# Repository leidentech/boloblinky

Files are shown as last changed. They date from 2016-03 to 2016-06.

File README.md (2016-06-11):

# Boloblinky retro game device made with a max7219 LED matrix and Arduino Nano

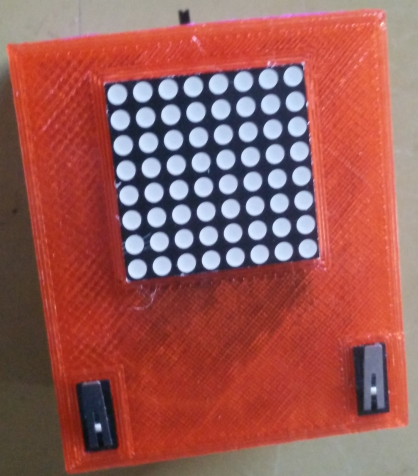
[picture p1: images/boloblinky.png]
boloblinky Boloblinky


I originally made this as a swag bag tchotchke for my 11-year-old son's birthday party.  It is designed so that the kids could build it themselves and get an introduction to soldering and acquainted with micro-controllers, programming and making stuff. My only two design parameters is that it had to be easy and relatively cheap - it had to be under/around €10 and came in at €9.81 including the PLA for the case and 4 batteries.

I decided on the nano and the max7219 because I've used them both before and I knew there were libraries for them that were easy to use and I could get both for under €3 each, leaving around €4 for the rest of the parts.

The program has different functions, which are incremented or decremented by long pressing the left or right button:

* 6-side die - hit either button to roll the die

* magic 8-ball type random advice giver - either button to get feedback

* image editor - hit the left button to go through the matrix pixel by pixel and the right button to turn it on or off.  When finished, long press either button to display the image

* race game - hit left or right to navigate through the random road.

* eyeball - animated eye that blinks and does crazy spins (eye code heavily borrows from work at https://github.com/michaltj/LedEyes/blob/master/LedEyes.ino)

* Timer, counts down a minute

The race game is something similar to one of the first programs I ever wrote on the Sinclair ZX81 a long time ago and reminiscent of the Mattel Electronics games I played in the '70s.  I had ideas of other games but since there are only two buttons the possibilities are limited.

Libraries used are: the Adafruit GFX library -  https://github.com/adafruit/Adafruit-GFX-Library and the Max72xxPanel library https://github.com/markruys/arduino-Max72xxPanel.git

## Build

OpenSCAD and STL files for this device can be found in the case directory.  There is also an alternate design with the micro switches inside the case.  My son preferred the switches on the outside.

Battery case:

place battery ends in the case so that the spring is at the end nearest the square plug bracket at the end where the switch is. Wire the nearest spring end underneath the bracket to the middle pin of the slide switch.   Wire the nearest pin of the slide switch to the (-) end of the two pin plug passing the wire underneath and through the bracket.

Wire the farthest flat end on the same side with a red wire to (+) side of the two pin plug passing the wire underneath and through the bracket.

Switches and Nano

wiring

Attach two wires with female plugs to the GND/VIN on the Nano next to the RST pin.

Wire the two pins nearest the bottom wall on the switches together, wire the middle pin on the switch nearest the Nano to D2 and the middle pin of the other switch to D3.  Wire the remaining pin on the switch nearest the Nano to GND next to D2 on the Nano.  Wire the remaining pin on the far switch with a female plug to go into the GND of the max7219.

Wire (with female plugs) the Nano's D10 to go to DIN on the max7219, The D11 to go to the CS pin on the max7219 and D13 to the CLK pin on the max7219.  Wire the 5V pin on the Nano to the 5V on the max7219.

This wiring corresponds to the Nano code and the libraries used.

Plug all the wires into the max7219 correctly and place that in the opening flush with the face of the top. Bend the pins as necessary to make the fit tight.  Slide the Nano into the slot so that the usb port is sticking out of the provided hole.

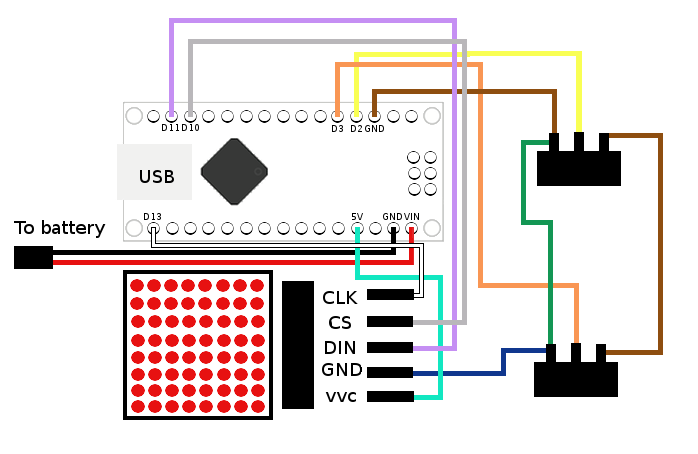
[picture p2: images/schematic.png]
schematic


## PARTS LIST
Prices will undoubtedly change:

| Price | Part | link |
| --- | --- | --- |
| €2.12 | Arduino Nano | http://www.banggood.com/5Pcs-ATmega328P-Nano-V3-Controller-Board-For-Arduino-Improved-Version-p-951797.html |
| €2.07 | MAX7219 Red Dot Matrix Module | http://www.banggood.com/5Pcs-MAX7219-Dot-Matrix-Module-MCU-LED-Control-Module-Kit-For-Arduino-p-1031709.html |
| €0.80/4 | Batteries | |
| €0.56 | Slide Switch | http://nl.farnell.com/c-k-components/os102011ma1qn1/switch-spdt-0-1a-12v-pcb-r-a/dp/1201431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 - I've since seen cheaper slide switches - such as http://www.banggood.com/20PCS-Black-Mini-Size-SPDT-Slide-Switches-On-Off-PCB-5V-0_3A-DIY-Material-p-1009183.html |
| €1.73 | Battery Contacts 3x€.41 .21 .24 | http://nl.farnell.com/keystone/5212/battery-dual-contact-a-aa/dp/1650703?CMP=i-bf9f-00001000 http://nl.farnell.com/keystone/5224/battery-pos-a-aa/dp/1650704?CMP=i-bf9f-00001000 http://nl.farnell.com/keystone/5201/battery-holder-a-aa-1way/dp/1339845?CMP=i-bf9f-00001000 |
| €0.42/2 | Microswitches | http://www.banggood.com/5pcs-Ultra-Mini-Actuator-Microswitch-SPDT-Sub-Miniature-Micro-Switch-p-1045857.html |
| €1.44 | PLA for Case | |
| €0.10 | Wire | |

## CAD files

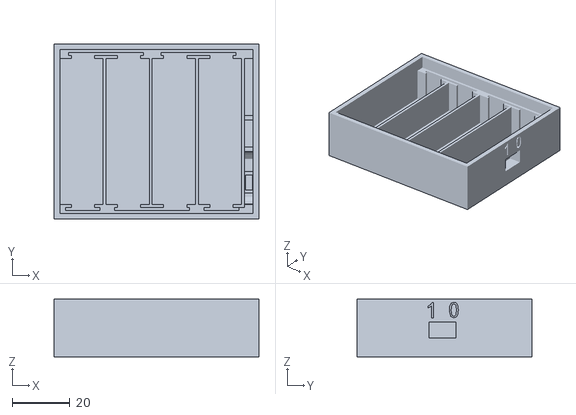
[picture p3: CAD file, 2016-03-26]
case/bottom.stl
71.0 x 60.7 x 20.0

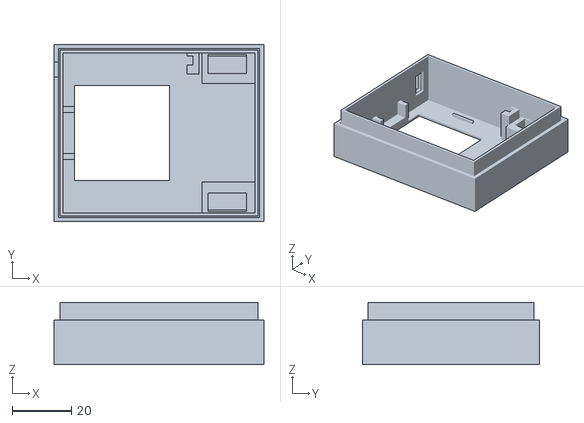
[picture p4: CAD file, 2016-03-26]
case/top-covered.stl
71.0 x 60.0 x 21.0

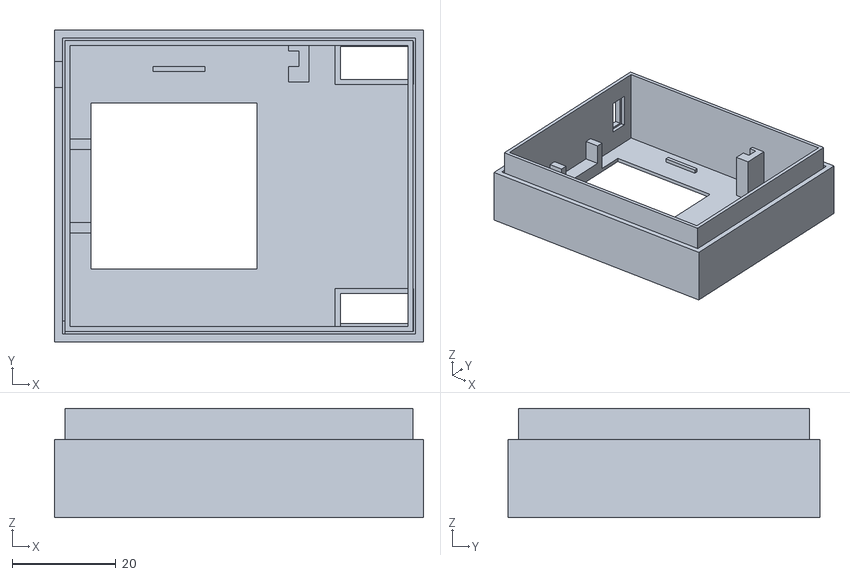
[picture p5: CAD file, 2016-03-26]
case/top.stl
71.0 x 60.0 x 21.0

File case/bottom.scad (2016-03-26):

/*
 * @copyright Copyright (C) 2016 Leiden Tech. All rights reserved.
 * @license http://www.gnu.org/licenses/gpl-3.0.txt GNU General Public License v3
 * 
 * The Write.scad library can be found at http://www.thingiverse.com/thing:16193 or https://github.com/rohieb/Write.scad.git 
 */
use <Write.scad/Write.scad>
$slotsize=1.1;
$outsidewall=2;
$wall=2;
$height=13;
$length=71;
$totalheight=20;
center=false;
//AA
$l = 50.5; $w = 14.5;$gap=.5;
t=3;
      
difference(){ //outside wall ends
//bigbox
cube ([$length, $l+$wall*2+$slotsize*2+$outsidewall*2, $totalheight]);
//cutout
translate([$outsidewall,$outsidewall,$height+$wall])     
cube ([$length-$outsidewall*2, $l+$wall*2+$slotsize*2, $totalheight-$height]);
//slide switch
translate([$length-$outsidewall-3,25,$height/2])    
    cube ([8,9.3,5.5]);
    
rotate([90,0,270])
   translate([-11.1,15,-69.5])
   write("+",t=t-2,h=$height/4+2,center=center);
rotate([90,0,270])
   translate([-17,15,-69.5])
   write("-",t=t-2,h=$height/4+2,center=center);
    
rotate([90,0,90])
   translate([24,13.5,70])
   write("1",t=t-2,h=$height/4+2,center=center);
rotate([90,0,90])
   translate([32,13.5,70])
   write("0",t=t-2,h=$height/4+2,center=center);

//wires
translate([$wall,$wall,$height])    
    cube ([$length-$wall*2,2,2]); 
translate([$length-$wall*2-1,$wall*2,$height])    
    cube ([3,3,2]); 
translate([$length-$wall*2-3,$wall,$height-$wall])    
    cube ([5,2.1,6]);
translate([$length-$wall*2-1,$wall*2,$height-$wall])    
    cube ([3,2,2]);
//1
$index=2;
echo ($index);
translate([$index,$wall*1.5+$slotsize+$outsidewall/2,$wall])     
cube ([$w+$gap, $l, $height]);

translate([$index+$wall*2,$wall+$outsidewall/2,$wall])     
cube ([8, $l+$wall*2, $height]);


translate([$index+$wall,$wall+$outsidewall/2,$wall])     
cube ([12, $slotsize, $height]);
    
translate([$index+$wall*1.5,$l+$wall*2+$slotsize+$outsidewall/2,$wall])     
cube ([13, $slotsize, $height]);  
  
    
//2
$index2=18;
echo ($index2);
translate([$index2,$wall*1.5+$slotsize+$outsidewall/2,$wall])     
cube ([$w+$gap, $l, $height]);

translate([$index2+$wall*2,$wall+$outsidewall/2,$wall])     
cube ([8, $l+$wall*2, $height]);

translate([$index2+$wall*1.5,$wall+$outsidewall/2,$wall])     
cube ([13, $slotsize, $height]);
    
translate([$index2,$l+$wall*2+$slotsize+$outsidewall/2,$wall])     
cube ([13, $slotsize, $height]);  


//3
$index3=34;
echo ($index3);
translate([$index3,$wall*1.5+$slotsize+$outsidewall/2,$wall])     
cube ([$w+$gap, $l, $height]);

translate([$index3+$wall*2,$wall+$outsidewall/2,$wall])     
cube ([8, $l+$wall*2, $height]);

translate([$index3,$wall+$outsidewall/2,$wall])     
cube ([13, $slotsize, $height]);
    
translate([$index3+$wall*1.5,$l+$wall*2+$slotsize+$outsidewall/2,$wall])
cube ([13, $slotsize, $height]);  

//4
$index4=50;
echo ($index4);
translate([$index4,$wall*1.5+$slotsize+$outsidewall/2,$wall])
//battery
cube ([$w+$gap, $l, $height]);
//end cutout
translate([$index4+$wall*2,$wall+$outsidewall/2,$wall])     
cube ([8, $l+$wall*2, $height]);
 //left end    
translate([$index4+$wall,$wall+$outsidewall/2,$wall])
cube ([12, $slotsize, $height]);
//right end
translate([$index4,$l+$wall*2+$slotsize+$outsidewall/2,$wall])
cube ([13, $slotsize, $height]);      
       
//extra slot
$index5=66;
translate([$index5,$wall*1.5+$slotsize+$outsidewall/2,$wall])     
cube ([3, $l, $height]);
} 

difference() { 
//switch support
translate([66,$l/2+$wall+$slotsize+$outsidewall/2-6,$wall])     
cube ([4, 12.5, $height-3]);
 //slide switch
translate([$length-$outsidewall-3,25,$height/2])    
cube ([8,9.3,5.5]);   
}

//power plug
difference() { 
translate([66,$wall*1.5+6,$wall+5]) 
cube([4, 7.5, $height-8]);
translate([66.3,$wall*3+4.1,$wall+5] )  
cube([2.5, 5.2, $height-3]); 
rotate([90,0,0])
translate([67.4,6.5,-18])
cylinder(r=2,h=10); 
}
//lets curve this so it's easier to move the wires
difference () {
translate([65,$wall*2+1.2,$wall]) 
cube([4, 18, 5]);
rotate([90,0,90])
translate([14.3,9.5,66])
cylinder(r=10,h=10);  
}

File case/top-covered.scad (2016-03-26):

/*
 * @copyright Copyright (C) 2016 Leiden Tech. All rights reserved.
 * @license http://www.gnu.org/licenses/gpl-3.0.txt GNU General Public License v3
 * 
 */
//covered switches boloblinky variation

$wall=1;
$height=15;
$length=71;
$width=60;
$totalheight=20;
$screen=32;

difference (){
 translate([0,0,0])  
 cube ([$length, $width, $height]);

 //cutout
 translate([$wall*1.5,$wall*1.5,$wall]) 
 cube ([$length-$wall*3, $width-$wall*3, $totalheight]);

 //screen
 translate([5+$wall*2,($width-$screen)/2,0])
 cube ([$screen, $screen, $wall]); 
    
 //button top cutout  
 translate([$length-$wall*2-17,$wall*2+1,0])  
 cube ([16, 8, $wall]);
 translate([$length-$wall*2-17,$width-11,0])  
 cube ([16, 8, $wall]);

 //usb hole
 translate([$wall-2,$width-11,5.5+$wall])  
 cube ([5, 5, 9]);
}
//button top cutout fill  
translate([$length-$wall*2-17,$wall*3+1,0])  
cube ([15, 6, $wall]);
translate([$length-$wall*2-17,$width-5-5,0])  
cube ([15, 6, $wall]);

difference()
{ //totalheight box
 translate([$wall*2,$wall*2,$wall])  
 cube ([$length-$wall*3-1, $width-$wall*3-1, $totalheight]);
 //inner cutout
 translate([$wall*3,$wall*3,$wall])  
 cube ([$length-$wall*4-2, $width-$wall*4-2, $totalheight]);

 //usb hole
 translate([$wall-2,$width-11,5.5+$wall])  
 cube ([5, 5, 9]); 
}
//nano align
translate([$wall+18,$width-8,$wall+.4])  
cube ([10, 1, 1]);


//max7219 pillow
difference()
{
 translate([$wall*2,$width/2-9,$wall])  
 cube ([5, 18, 8]);
 translate([$wall*2,$width/2-7,3.5])  
 cube ([5, 14, 8]);
}

//buttons housing
translate([$length-$wall*2-19,$wall+10.5,0])  
cube ([18, $wall*2, 10]);

translate([$length-$wall*2-19,$wall+1.5,4])
difference (){
 cube ([18, 10, 6]);
 translate([2,.9,0])  
 cube ([13.1, 6.3, 6]);
}

translate([$length-$wall*2-19,$width-13.2,0])  
cube ([18, $wall*2, 10]);

translate([$length-$wall*2-19,$width-12,4])  
difference (){
 cube ([18, 9, 6]);
 translate([2,2.2,0])  
 cube ([13.1, 6.3, 6]);
}
//end button housing

//nano end wall
difference() {
 translate([$wall*2+43,$width-10,$wall])  
 cube ([4, 7, 12]);
 translate([$wall*2+43,$width-7,$wall])  
 cube ([2, 3, 12]);
}

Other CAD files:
case/top.scad

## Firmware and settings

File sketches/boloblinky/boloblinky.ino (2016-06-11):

/*
 * @copyright Copyright (C) 2016 Leiden Tech. All rights reserved.
 * @license http://www.gnu.org/licenses/gpl-3.0.txt GNU General Public License v3
 * 
 */
#include <SPI.h>
//This is for text operations by Max72xxPanel used in msgBoard - has to come before the  Max72xxPanel
#include <Adafruit_GFX.h>
#include <Max72xxPanel.h>

//screen setup - don't really need this since it's only going to be one display anyway
int numberOfHorizontalDisplays = 1;
int numberOfVerticalDisplays = 1;

#define MAX72XX_CS 10
//#define MAX72XX_DIN 11
//#define MAX72XX_CLK 13

byte screen[8]={
	B00000000,
	B00000000,
	B00000000,
	B00000000,
	B00000000,
	B00000000,
	B00000000,
	B00000000
};

int cursorIndex=0;

Max72xxPanel matrix = Max72xxPanel(MAX72XX_CS, numberOfHorizontalDisplays, numberOfVerticalDisplays);

//switch setup
int leftButton = 2;
int rightButton = 3;
boolean leftPress=false;
boolean rightPress=false;
boolean leftLongPress=false;
boolean rightLongPress=false;
boolean bothPress=false;
boolean modeFlag=false; //First time through flag

int longPressInterval=60; //The lower the debounce, the higher this must be
int debounce=10;
int mode=1;  //set this to whatever the default should be on start
String lang="eng";

int wait = 50; // In milliseconds

//Message board setup
int spacer = 1;
int fontWidth = 5 + spacer; // The font width is 5 pixels
String message;
//Any way to set the font?

long randNumber;

//Eye setup
byte eyeBall[8]={
	B00111100,
	B01111110,
	B11111111,
	B11111111,
	B11111111,
	B11111111,
	B01111110,
	B00111100
};

byte eyePupil = B11100111;

// stores current state of eye LEDs
byte eyeCurrent[8];
int currentX;
int currentY;
int cntLoop = 0;
int cntEffect = 0;

// min and max positions
#define MIN -2
#define MAX  2

// perform an effect every # of loop iterations, 0 to disable
#define EFFECT_ITERATION 4

//Race game setup
//Setting up new screen so that if edit doesn't wipe stored image
byte track[8]={
  B00000000,
  B00000000,
  B00000000,
  B00000000,
  B00000000,
  B00000000,
  B00000000,
  B00000000
};
int carPosition=3;
int raceScore=0;
int trackWidth=3;
int trackPos=2;
boolean inGame=false;

void wipe(boolean flag = LOW, int wipeWait = 2)
{ //fillscreen with delay 
	for ( int i = 0 ; i <= 7; i++ ) {
		for ( int j = 0 ; j <= 7; j++ ) {
			matrix.drawPixel(i, j, flag);
			matrix.write();
			delay(wipeWait);
		} 
	}
	delay(wait);
}

void setup() {
	Serial.begin(9600);
	matrix.setIntensity(7); // Use a value between 0 and 15 for brightness
	pinMode(leftButton, INPUT_PULLUP);
	pinMode(rightButton, INPUT_PULLUP);
	randomSeed(analogRead(0));
	//init
	transition();
	if ( lang == "dut" ) {
		msgBoard("Klaar");
	} else {
		msgBoard("Ready");
	}
	Serial.setTimeout(1);
}

void loop() {
	message = Serial.readString();
	delay(wait); //This has to be here and not in the if for the Serial read.
	if ( message != "") {
		//displays string from serial - doesn't work well - long string will timeout can't increase timeout because that increases loop delay for everything else - might be nice to be able to have a scrolling infinite message but I don't think people will be using this while it's plugged into a serial port somewhere anyway.
		//Serial.print("message: ");Serial.println(message);
		matrix.setRotation(0); 
		msgBoard(message);
	}
	
	getSwitch();
	
	if (leftLongPress) {
		transition();
		mode++;
		modeFlag=true;
		if (mode > 6) {
			mode=0;
		}
		inGame=false;
	} else if (rightLongPress) {
		transition();
		mode--;
		modeFlag=true;
		if (mode < 0) {
			mode=6;
		}
		inGame=false;
	}
	switch(mode)
	{
		case 0:
			matrix.setRotation(0);
			googlyEye();
			break;
		case 1:
			matrix.setRotation(0);
			if (!modeFlag && leftPress || rightPress) {
				sequence();
			}
			break;     
		case 2:
			matrix.setRotation(0);
			if (!modeFlag && leftPress || rightPress) {
				magic8ball();
			}
			break;  
		case 3:
			if (modeFlag) { //to reset the race if mode is changed during play
				byte track[8]={
					B00000000,
					B00000000,
					B00000000,
					B00000000,
					B00000000,
					B00000000,
					B00000000,
					B00000000
				};
				carPosition=3;
				raceScore=0;
				inGame=true;
			} else {
				matrix.setRotation(1); 
				matrix.drawPixel(7, carPosition, LOW);
				matrix.write();
				delay(wait);
				if (leftPress) {
					delay(debounce);
					carPosition++;
					carPosition = constrain(carPosition, 0, 7);
					//Serial.print("left: ");Serial.println(carPosition);
				}
				if (rightPress) {
					delay(debounce);
					carPosition--;
					carPosition = constrain(carPosition, 0, 7);
					//Serial.print("right: ");Serial.println(carPosition);
				}
				matrix.write();
				race();
			}
			break;  
		case 4:
			if (modeFlag) { //We only want this to execute the first time through
				matrix.setRotation(1); 
				wipe();
				for ( int s = 0 ; s <= 7; s++ ) {
					//Serial.print("s: ");Serial.print(s);Serial.print(" value:");Serial.println(screen[s]);
					setRow(0,s,screen[s]);
				} 
				matrix.write();
			}
			if (leftPress && !modeFlag) {
				cursorIndex++;
				if (cursorIndex > 63) {
					cursorIndex=0;
				}
			} else if (rightPress && !modeFlag) {
				int x;
				int y;
				int oldstate;
				x = round(cursorIndex / 8);
				y = 7 - (cursorIndex % 8);
				oldstate = bitRead(screen[x], y);
				if ( oldstate == HIGH ) {
					bitWrite(screen[x], y, 0);
				}else{
					bitWrite(screen[x], y, 1);
				}
				setRow(0,x,screen[x]);
			}
			editScreen();
			break;       
		case 5:
			if (isBlank()) { //Skip display if stored image is blank - shouldn't be followed by something that uses modeFlag because that will get stripped here if blank.
				if (leftLongPress) {
					mode++;
				} else {
					mode--;
				}
				break;
			}
			if (modeFlag) { //We only want this to execute the first time through otherwise it flickers
				matrix.setRotation(1); 
				wipe();
				for ( int s = 0 ; s <= 7; s++ ) {
					//Serial.print("s: ");Serial.print(s);Serial.print(" value:");Serial.println(screen[s]);
					setRow(0,s,screen[s]);
				} 
				matrix.write();
			}
			break;
		case 6:
			if (!modeFlag && leftPress || rightPress) {
				timer();
			}
			break;
		default: //should never get here
			break;
	}
	//switch reset
	modeFlag=false;
	bothPress=false;
	leftPress=false;
	rightPress=false;
	leftLongPress=false;
	rightLongPress=false;
}

void getSwitch()
{
	int leftLongCount=0;
	int rightLongCount=0;
	while(digitalRead(leftButton) == LOW) { //is being pressed
		leftPress=true;
		if (digitalRead(rightButton) == LOW) {
			bothPress = true;
		}
		delay(debounce);
		leftLongCount++; //For long press
		if (digitalRead(leftButton) == HIGH) { //Lifted
			break;
		}
		if (leftLongCount > longPressInterval){
			leftLongPress=true;
			break;
		}
	}
	if (bothPress) { //don't have to check other button if this is true unless you want right long on both triggered.
		rightPress=true;
		return;
	}
	while(digitalRead(rightButton) == LOW) { //is being pressed
		rightPress=true;
		delay(debounce);
		rightLongCount++; //For long press
		if (digitalRead(rightButton) == HIGH) { //Lifted
			break;
		}
		if (rightLongCount > longPressInterval){
			rightLongPress=true;
			break;
		}
	}
}

void transition()
{ //Between modes
	matrix.fillScreen(HIGH);
	matrix.write();
	delay(500);
	matrix.fillScreen(LOW);
	matrix.write();
}
void timer()
{ //1-minute timer... every second lights up another pixel
	matrix.fillScreen(LOW);
	matrix.write();
	matrix.setRotation(1);
	setRow(0, 7, 15); //64 pixels but 60 seconds - lets preload the last 4
	int x;
	int y;
	for ( int cursorIndex = 0 ; cursorIndex <= 59; cursorIndex++ ) {  //Once countdown starts, no way to break out, that's maybe annoying
		x = round(cursorIndex / 8);
		y = 7 - (cursorIndex % 8);
		matrix.drawPixel(x, y, HIGH);
		matrix.write();
		delay(1000);
	}
	matrix.fillScreen(LOW);
	matrix.write();
}

void editScreen()
{	//left button move cursor++, right button flips value - blink under cursor is min intensity if bit is not set, max if it is set
	matrix.setRotation(1); 
	int x;
	int y;
	int oldstate;
	x = round(cursorIndex / 8);
	y = 7 - (cursorIndex % 8);
	//Serial.print("x: ");Serial.print(x);Serial.print(" y: ");Serial.print(y);Serial.print(" state: ");Serial.println(oldstate);
	oldstate = bitRead(screen[x], y);
	cursorBlink(x,y,oldstate);
	matrix.write();
}

void cursorBlink(int x,int y,int state)
{ //blinks cursor - fast cursor if underlying pixel is set slow if not set
	if ( state == 1 ) { //IS ALREADY ON
		matrix.setIntensity(12);
	} else {
		matrix.setIntensity(7);
	}
	matrix.drawPixel(x, y, LOW);
	matrix.write();
	delay(10);
	matrix.drawPixel(x, y, HIGH);
	matrix.write();
	setRow(0,x,screen[x]);
}

boolean isBlank()
{ //checks to see if screen used in edit mode is blank
	int total=0;
	for ( int i = 0 ; i <= 7; i++ ) {
		total = total + screen[i];
	}
	if (total == 0) return true;
	return false;
}

void msgBoard(String message)
{ //Scrolling text message
	for ( int i = 0 ; i < fontWidth * message.length() + matrix.width() - 1 ; i++ ) {
		matrix.fillScreen(LOW);
		int letter = i / fontWidth;
		int x = (matrix.width() - 1) - i % fontWidth;
		int y = (matrix.height() - 8) / 2; // center the text vertically

		while ( x + fontWidth - spacer >= 0 && letter >= 0 ) {
			if ( letter < message.length() ) {
				matrix.drawChar(x, y, message[letter], HIGH, LOW, 1);
			}
			letter--;
			x -= fontWidth;
		}
		matrix.write(); // Send bitmap to display
		delay(wait);
	} 
}

void sequence()
{ //Doesn't have to be a die - could be any animation
	int i=0;
	int index;
  
	byte numbers[48]={ //This for nice numbers - not used
		B00011000,
		B00111000,
		B01111000,
		B00011000,
		B00011000,
		B00011000,
		B01111110,
		B00000000,
		B00111100,
		B01100110,
		B01000110,
		B00001100,
		B00011000,
		B00110000,
		B01111110,
		B00000000,
		B00111100,
		B01100110,
		B00000110,
		B00001100,
		B00000110,
		B01100110,
		B00111100,
		B00000000,
		B01100110,
		B01100110,
		B01100110,
		B01111110,
		B00000110,
		B00000110,
		B00000110,
		B00000000,
		B01111110,
		B01100000,
		B01100000,
		B01111100,
		B00000110,
		B01000110,
		B00111100,
		B00000000,
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
	};
  
	byte pips[48]={
		B00000000,
		B00000000,
		B00000000,
		B00011000,
		B00011000,
		B00000000,
		B00000000,
		B00000000,
		B00000000,
		B00000011,
		B00000011,
		B00000000,
		B00000000,
		B11000000,
		B11000000,
		B00000000,
		B00000000,
		B00000011,
		B00000011,
		B00011000,
		B00011000,
		B11000000,
		B11000000,
		B00000000,
		B00000000,
		B11000011,
		B11000011,
		B00000000,
		B00000000,
		B11000011,
		B11000011,
		B00000000,
		B00000000,
		B11000011,
		B11000011,
		B00011000,
		B00011000,
		B11000011,
		B11000011,
		B00000000,
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
	};
	matrix.setRotation(1);
	randNumber = random(6);
	// Serial.print("rando: ");  
	// Serial.println(randNumber);
	wipe(); 
	// for ( int i = 0 ; i <= 8; i++ ) {  /To scroll from one number to the next - bit too slow
		for ( int j = 0 ; j <= 7; j++ ) {
			index=(8*randNumber+i+j)%48;
			setRow(0, j, pips[index]);
		}
	//}
	matrix.setRotation(0);
}

void rollDice()
{ //uses drawChar to render number - not used
	randNumber = random(6);
	wipe();
	matrix.drawChar(1, 0, char(49+randNumber), HIGH, LOW, 1);
	matrix.write();
}

void setRow(int addr, int row, byte rowValue)
{
	for (int n=0; n<=7; n++)
	{
	matrix.drawPixel(row, n, bitRead(rowValue, n));
	}
	matrix.write();
}

void magic8ball()
{ //Arduinos apparently really, really don't like arrays of strings - without the F macro to tell it to keep your strings in PROGMEM the global variables in the sketch go above 60% dynamic memory and random bad things happened
	randNumber = random(20);
    
	if ( lang == "dut" ) {     
		String dutAnswer[20]={
			F("Het is zeker"),
			F("Het is beslist zo"),
			F("Zonder twijfel"),
			F("Zeer zeker"),
			F("Je kunt erop vertrouwen"),
			F("Volgens mij wel"),
			F("Zeer waarschijnlijk"),
			F("Goed vooruitzicht"),
			F("Ja"),
			F("Tekenen wijzen op ja"),
			F("Reactie is wazig, probeer opnieuw"),
			F("Vraag later opnieuw"),
			F("Beter je nu niet te zeggen"),
			F("Niet nu te voorspellen"),
			F("Concentreer en vraag opnieuw"),
			F("Reken er niet op"),
			F("Mijn antwoord is nee"),
			F("Mijn bronnen"),
			F("Vooruitzicht is niet zo goed"),
			F("Zeer twijfelachtig")
		};
		//Serial.print("Dutch randNumber: ");Serial.print(randNumber);Serial.print(" answer: ");Serial.println(dutAnswer[randNumber]);
		msgBoard(dutAnswer[randNumber]);  
	} else {
		String engAnswer[20]={
			F("It is certain"),
			F("It is decidedly so"),
			F("Without a doubt"),
			F("Yes, definitely"),
			F("You may rely on it"),
			F("As I see it, yes"),
			F("Most likely"),
			F("Outlook good"),
			F("Yes"),
			F("Signs point to yes"),
			F("Reply hazy try again"),
			F("Ask again later"),
			F("Better not tell you now"),
			F("Cannot predict now"),
			F("Concentrate and ask again"),
			F("Don't count on it"),
			F("My reply is no"),
			F("My sources say no"),
			F("Outlook not so good"),
			F("Very doubtful")
		};
		//Serial.print("English randNumber: ");Serial.print(randNumber);Serial.print(" answer: ");Serial.println(engAnswer[randNumber]);
		msgBoard(engAnswer[randNumber]); 
	}

}

//EYES Start - based on code from https://github.com/michaltj/LedEyes
void googlyEye()
{
	int times=2;
	byte row = eyePupil;
	matrix.setRotation(1);
	// move to random position, wait random time
	moveEyes(random(MIN, MAX + 1), random(MIN, MAX + 1), 50);
	delay(random(5, 7) * 500);
	
	// blink time?
	if (random(0, 5) == 0)
	{
		delay(500);
		blinkEye();
		delay(500);
	}
	
	// effect time?
	if (EFFECT_ITERATION > 0)
	{
		cntLoop++;
		if (cntLoop == EFFECT_ITERATION)
		{
			cntLoop = 0;
			if (cntEffect > 2) cntEffect = 0;
			switch(cntEffect)
			{
				case 0:
					//roundSpin
					for (int i=0; i<times; i++)
					{
						displayEyes(2, -1); delay(40); if (i==0) delay(40);
						displayEyes(1, -2); delay(40); if (i==0) delay(30);
						displayEyes(0, -2); delay(40); if (i==0) delay(20);
						displayEyes(-1, -2); delay(40);if (i==0) delay(10);
						displayEyes(-2, -1); delay(40);
						displayEyes(-2, 0); delay(40);
						displayEyes(-2, 1); delay(40);if (i==(times-1)) delay(10);
						displayEyes(-1, 2); delay(40);if (i==(times-1)) delay(20);
						displayEyes(0, 2); delay(40); if (i==(times-1)) delay(30);
						displayEyes(1, 2); delay(40); if (i==(times-1)) delay(40);
						displayEyes(2, 1); delay(40); if (i==(times-1)) delay(50);
						displayEyes(2, 0); delay(40);
					}
					break;
				case 1:
					//center row Spin
					moveEyes(0, 0, 50);
					for (int t=0; t<times; t++)
					{
						// spin from center to L
						for (int i=0; i<5; i++)
						{
							row = row >> 1;
							row = row | B10000000;
							setRow(0, 3, row);  
							setRow(0, 4, row); 
							delay(50); 
							if (t == 0) 
								delay((5-i)*10); // increase delay on 1st scroll (speed up effect)
						}
						// spin from R to center
						for (int i=0; i<5; i++)
						{
							row = row >> 1;
							if (i>=2) 
								row = row | B10000000;
							setRow(0, 3, row);
							setRow(0, 4, row);
							delay(50);
							if (t == (times-1)) 
								delay((i+1)*10); // increase delay on last scroll (slow down effect)
						}
					}
					break;
				case 2:
					blinkEye();
					break;
				default: 
					break;
			}
			delay(1000);
			cntEffect++;
		}
	}
	matrix.setRotation(0);
}

void blinkEye()
{
	// close eyelids
	for (int i=0; i<=3; i++)
	{
		setRow(0, i, 0);
		setRow(0, 7-i, 0);
		delay(wait);
	}
	// open eyelids
	for (int i=3; i>=0; i--) 
	{
		setRow(0, i, eyeCurrent[i]);
		setRow(0, 7-i, eyeCurrent[7-i]);
		delay(wait);
	}
}

void displayEyes(int offsetX, int offsetY) 
{
	// ensure offsets are  in valid ranges
	offsetX = constrain(offsetX, MIN, MAX);
	offsetY = constrain(offsetY, MIN, MAX);
	
	// calculate indexes for pupil rows (perform offset Y)
	int row1 = 3 - offsetY;
	int row2 = 4 - offsetY;
	
	// define pupil row
	byte pupilRow = eyePupil;
	
	// perform offset X
	// bit shift and fill in new bit with 1 
	if (offsetX > 0) {
		for (int i=1; i<=offsetX; i++)
		{
			pupilRow = pupilRow >> 1;
			pupilRow = pupilRow | B10000000;
		}
	}
	else if (offsetX < 0) {
		for (int i=-1; i>=offsetX; i--)
		{
			pupilRow = pupilRow << 1;
			pupilRow = pupilRow | B1;
		}
	}
	
	// pupil row cannot have 1s where eyeBall has 0s
	byte pupilRow1 = pupilRow & eyeBall[row1];
	byte pupilRow2 = pupilRow & eyeBall[row2];
	
	// display on LCD matrix, update to eyeCurrent
	for(int r=0; r<8; r++)
	{
		if (r == row1)
		{
			setRow(0, r, pupilRow1);
			eyeCurrent[r] = pupilRow1;
		}
		else if (r == row2)
		{
			setRow(0, r, pupilRow2);
			eyeCurrent[r] = pupilRow2;
		}
		else
		{
			setRow(0, r, eyeBall[r]);
			eyeCurrent[r] = eyeBall[r];
		}
	}
	
	// update current X and Y
	currentX = offsetX;
	currentY = offsetY;
}

void moveEyes(int newX, int newY, int stepDelay)
{
	// set current position as start position
	int startX = currentX;
	int startY = currentY;
	
	newX = constrain(newX, MIN, MAX);
	newY = constrain(newY, MIN, MAX);
	
	// eval steps
	int stepsX = abs(currentX - newX);
	int stepsY = abs(currentY - newY);
	
	// need to change at least one position
	if ((stepsX == 0) && (stepsY == 0))
		return;
	
	// eval direction of movement, # of steps, change per X Y step, perform move
	int dirX = (newX >= currentX) ? 1 : -1;
	int dirY = (newY >= currentY) ? 1 : -1;
	int steps = (stepsX > stepsY) ? stepsX : stepsY;
	int intX, intY;
	float changeX = (float)stepsX / (float)steps;
	float changeY = (float)stepsY / (float)steps;
	for (int i=1; i<=steps; i++)
	{
		intX = startX + round(changeX * i * dirX);
		intY = startY + round(changeY * i * dirY);
		displayEyes(intX, intY);
		delay(stepDelay);
	}
}
//EYES end

void race()
{
	byte randomTrack;
	byte trackChunk;
	int oldTrackPos;
	int oldWidth;
	int minPos;
	int maxPos;
	int randomPos;
	matrix.setRotation(1);
	//Serial.println("in race");

	//Shift screen down
	for ( int i = 7 ; i >= 1; i-- ) {
		track[i]=track[i-1];
	}

	//car in wall now? boom otherwise increment score
	if (bitRead(track[7], carPosition) == HIGH ) {
		matrix.setRotation(0);
		msgBoard("Score: "+ (String) raceScore);
		for ( int i = 0 ; i <= 7; i++ ) {
			track[i]=0;
		}
		raceScore=0;
		inGame=false;
		return;
	} else {
		raceScore++;
	}
	oldWidth = trackWidth;
	trackWidth = constrain(random(2) + 2 ,2,4);//Should be between 2 and 4

	oldTrackPos = trackPos;
	minPos=constrain(oldTrackPos-round(min(trackWidth,oldWidth)/2-.5),1,7-trackWidth);
	maxPos=oldTrackPos+round(min(trackWidth,oldWidth)/2+.5);
	randomPos=random(maxPos-minPos)+minPos;
	trackPos = constrain(randomPos,minPos,maxPos);
	trackPos = constrain(trackPos,1,8-trackWidth);
	
	//Position new track opening
	trackChunk= 1 << trackWidth;
	trackChunk--;
	trackChunk = trackChunk << constrain(trackPos,1,7-trackWidth);  
	track[0] = trackChunk ^ B11111111;
	//draw screen
	for ( int i = 0 ; i <= 7; i++ ) {
		setRow(0,i,track[i]);
	}
	//draw car position
	matrix.drawPixel(7, carPosition, HIGH);
	matrix.write();
	delay(500-constrain(raceScore,0,500)); //Get faster the longer it's played
}
